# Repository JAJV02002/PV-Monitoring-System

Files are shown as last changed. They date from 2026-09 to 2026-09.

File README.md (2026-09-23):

# ☀️ PV Monitoring System

A photovoltaic monitoring project combining an ESP32 measurement unit, a PHP/MySQL web application, PCB designs and a printable enclosure. Developed for a bachelor’s thesis, the repository brings together the hardware and software resources for studying and recreating the system.





## 🌟 Features

- **Electrical measurements:** RMS voltage, RMS current, apparent power and an accumulated energy estimate.
- **Wi-Fi telemetry:** ESP32 measurements sent to the web application using HTTPS form requests.
- **Web dashboard:** Spanish and English interfaces with charts and historical readings.
- **Device management:** Devices grouped into matrices and measurement points.
- **Hardware resources:** KiCad schematic, board layout, required custom libraries, manufacturing outputs and a PCB assembly model.
- **Printable enclosure:** Separate STL files for the base and lid.

## 📁 Repository Structure

```text
PV-Monitoring-System/
├── hardware/
│   ├── bom/
│   │   └── EMON_BOM.xlsx
│   ├── cad/
│   │   ├── enclosure-base.stl
│   │   └── enclosure-lid.stl
│   └── pcb/
│       ├── kicad/
│       │   ├── monitoring-board.kicad_pro
│       │   ├── monitoring-board.kicad_sch
│       │   └── monitoring-board.kicad_pcb
│       ├── gerber/pcb-manufacturing.zip
│       └── 3d/pcb-assembly.zip
├── software/
│   ├── firmware/
│   │   ├── src/main.cpp
│   │   ├── include/secrets.example.h
│   │   └── platformio.ini
│   └── webapp/
│       ├── app/
│       ├── resources/
│       ├── index.php
│       └── .env.example
└── docs/
    └── architecture.md
```

Each component directory includes its own README with configuration and usage instructions.

## 🚀 Quick Start

### 1. Prepare the Hardware

1. Review the [Excel bill of materials](hardware/bom/EMON_BOM.xlsx).
2. Open the [KiCad project](hardware/pcb/kicad/README.md) and inspect the circuit and board layout.
3. Review the [manufacturing files](hardware/pcb/gerber/README.md) before ordering a PCB.
4. Inspect and print the [enclosure base and lid](hardware/cad/README.md), checking scale and fit against the board.

### 2. Configure the Web Application

Set up Apache, PHP with `mysqli`, and MySQL. Follow the [web application guide](software/webapp/README.md) to configure the document root, HTTPS and database connection.

```sh
cd software/webapp
cp .env.example .env
```

Enter the database credentials and a random hexadecimal device key in `.env`. A compatible database schema is required; the standalone schema is not yet published. See [database requirements](software/webapp/database/README.md).

### 3. Configure and Upload the Firmware

```sh
cd software/firmware
cp include/secrets.example.h include/secrets.h
```

Set the Wi-Fi credentials, HTTPS endpoint and matching device key in `secrets.h`, then build and upload:

```sh
pio run
pio run --target upload
pio device monitor
```

### 4. Connect the Measurement Point

Register the device with the web application, associate it with a measurement point, and confirm that readings appear in the database and dashboard. Check calibration against a suitable reference instrument.

## 📊 System Architecture

```text
Voltage and current signals
            │
            ▼
      ESP32 + sensors
  Sampling · RMS · Calibration
            │
            │ Wi-Fi / HTTPS form POST
            ▼
      PHP web application
    Controllers · Models · Views
            │
            ├── MySQL measurement storage
            │
            ▼
       Web dashboard
   Live views · History · Charts
```

## 🔧 Hardware

The Excel BOM contains core components and a high-precision sensing configuration, including the ESP32-DEVKITC-32E, HCPL-7800A-300E, OP177GSZ and HXS20-NP. Use the workbook as the component list and check compatibility with the intended PCB revision before assembly.

The manufacturing job describes a **two-layer, 1.6 mm board**, approximately **100.4 × 70.4 mm**. The enclosure is available as STL meshes, and the PCB assembly is available as a STEP model.

## 💻 Software Stack

| Component | Technology |
| --- | --- |
| Firmware | C++ / Arduino framework / PlatformIO |
| Microcontroller target | ESP32 development board (`esp32dev`) |
| Backend | PHP with an MVC-style structure |
| Database | MySQL through `mysqli` |
| Web server | Apache |
| Frontend | PHP views, HTML, CSS and JavaScript |
| Interface libraries | Bootstrap, Chart.js, jQuery and Popper |
| Telemetry | HTTPS with URL-encoded form fields |

## 📈 Measurement Details

- **ADC inputs:** GPIO 34 for voltage and GPIO 35 for current.
- **Sampling:** 12-bit resolution, 1,000 samples per block.
- **Averaging:** Voltage and current averaged over five blocks.
- **Power:** Apparent power calculated as `Vrms × Irms`.
- **Energy:** Time-integrated estimate assuming unity power factor; resets at restart.

The offset filter removes the DC component. Calibration and supported electrical ranges must be verified for the measurement hardware. See the [firmware guide](software/firmware/README.md) for timing and power-averaging details.

## 📖 Documentation

- [Hardware guide](hardware/README.md)
- [Bill of materials](hardware/bom/README.md)
- [Firmware setup](software/firmware/README.md)
- [Web application setup](software/webapp/README.md)
- [Database requirements](software/webapp/database/README.md)
- [Architecture and telemetry](docs/architecture.md)

## 📝 License
This project is licensed under the Creative Commons Attribution 4.0 License - see the [LICENSE](LICENSE.txt) file for details.

The web application is distributed under its existing [GNU GPL version 3 license](software/webapp/LICENSE). Third-party libraries retain their own notices. Separate licensing terms for the hardware, firmware and documentation are not yet specified.

## 🤝 Contributing

Improvements to documentation, reproducibility, hardware integration and software testing are welcome. Use repository issues to describe a problem or propose a change, and include the board revision and relevant configuration when reporting results.

## 🎓 Educational Use

The project supports study of embedded acquisition, electrical measurement, wireless telemetry and web-based monitoring in renewable-energy research.

## 🙏 Acknowledgments

- ESP32 and Arduino communities
- KiCad development community
- Bootstrap, Chart.js and other third-party library contributors

---

**Made with ❤️ for renewable energy monitoring**

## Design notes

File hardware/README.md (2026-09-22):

# 🔧 Hardware

PCB designs, enclosure models and component information for the monitoring unit.

## 📁 Files and Directories

| Directory | Contents |
| --- | --- |
| [bom](bom/README.md) | Excel component, quantity and cost tables |
| [cad](cad/README.md) | Enclosure base and lid STL meshes |
| [pcb/kicad](pcb/kicad/README.md) | Editable project, schematic, board layout and required custom libraries |
| [pcb/gerber](pcb/gerber/README.md) | Manufacturing layers and drill files |
| [pcb/3d](pcb/3d/README.md) | PCB assembly STEP model |

## 🚀 Build Preparation

1. Use [EMON_BOM.xlsx](bom/EMON_BOM.xlsx) to plan component purchases.
2. Open the KiCad project to inspect the schematic, footprints and board revision.
3. Review the manufacturing outputs before placing a PCB order.
4. Inspect the enclosure meshes and check their fit against the PCB assembly model.

## 📐 Board Details

The Gerber job specifies two copper layers, a 1.6 mm thickness and an approximate size of 100.4 × 70.4 mm. Check the intended revision and component compatibility before assembly.

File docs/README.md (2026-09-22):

# 📖 Project Documentation

Guides for understanding the monitoring system and recreating its hardware and software setup.

## 🚀 Recommended Reading Order

1. [Hardware](../hardware/README.md): components, enclosure, PCB and manufacturing resources.
2. [Web application](../software/webapp/README.md): Apache, PHP, database and device-key configuration.
3. [Firmware](../software/firmware/README.md): ESP32 configuration, build and upload.
4. [Architecture and telemetry](architecture.md): acquisition flow, request fields and data storage.

## 🔗 Additional Reference

- [Bill of materials](../hardware/bom/README.md)
- [Database requirements](../software/webapp/database/README.md)

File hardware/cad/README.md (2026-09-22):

# 🧩 Enclosure

Two STL meshes define the enclosure base and lid.

## 📁 Files

| File | Description |
| --- | --- |
| [enclosure-base.stl](enclosure-base.stl) | Enclosure base |
| [enclosure-lid.stl](enclosure-lid.stl) | Enclosure lid |

## 🖨️ Printing Preparation

1. Open both meshes in a CAD viewer or slicer.
2. Confirm the scale: STL files do not encode units.
3. Check board clearance and lid fit against the [PCB assembly model](../pcb/3d/README.md).
4. Select printing material, orientation and settings appropriate to the installation.

The files contain mesh geometry; editable parametric enclosure models are not included.

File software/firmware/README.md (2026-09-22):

# ⚡ ESP32 Firmware

ESP32 firmware for acquiring voltage and current signals, calculating electrical measurements and sending them to the web application. The program is in `src/main.cpp`; network credentials and the server URL belong in the local `include/secrets.h` file.

## ⚙️ Configuration

Copy the configuration template:

```sh
cp include/secrets.example.h include/secrets.h
```

Set `SERVER_URL` to your HTTPS endpoint ending in `/app/api.php`. The Apache configuration also accepts the previous `/app/app.php` URL for existing devices. Set `DEVICE_API_KEY` to the same value as the web application's `DEVICE_API_KEY`. Use a random hexadecimal key: the current firmware concatenates form fields without URL encoding, so characters such as `&`, `+` and `=` must not be used in that key.

Set `WIFI_SSID` and `WIFI_PASSWORD` for your local network. The network-selection routine starts with one configured entry. To add networks, define their credentials in the ignored `secrets.h` file and add the corresponding entries to `knownNetworks`.

Never commit `secrets.h`.

## 🚀 Build and Upload

The project targets an ESP32 development board (`esp32dev`) using the Arduino framework. Upload and serial-monitor speeds are both 115200 baud.

```sh
pio run
pio run --target upload
pio device monitor
```

PlatformIO installs the Espressif platform on the first build. Measurements are sent directly to the PHP application using the ESP32 Wi-Fi and HTTP libraries. The platform version is not pinned in `platformio.ini`; record the version used for your build so you can reproduce it later.

## 📈 Measurement Procedure

1. Read voltage on GPIO 34 and current on GPIO 35 with 12-bit ADC resolution.
2. Collect 1,000 samples per block and update the dynamic offset estimates.
3. Accumulate squared offset-corrected samples and calculate RMS values.
4. Apply the existing calibration coefficients and piecewise corrections.
5. Compute apparent power for the current block as `Vrms × Irms`.
6. Integrate that power over elapsed time into an energy estimate in Wh, assuming unity power factor.
7. Average voltage and current over five blocks and transmit the resulting values.

The transmitted power is the value from the final block, not the product of the five-block average RMS values. Energy is accumulated each block and is held only in RAM. It resets at restart. The routine includes a five-second delay after an upload attempt; acquisition and networking add to that interval, so transmission is not on an exact fixed-period schedule.

The ADC offset filter removes the DC component. Calibration coefficients are defined in `src/main.cpp`. Check and adjust them against your measurement hardware and a suitable reference instrument before using the readings.

## 📡 Telemetry

The firmware sends `_np`, `api_key`, `chipid`, `mac`, `voltaje`, `corriente`, `potencia` and `energia` as form fields. See [the protocol description](../../docs/architecture.md).

The HTTPS client calls `setInsecure()`, so it does not verify the server certificate. Configure certificate verification before using it on an untrusted network. An HTTP success response alone does not prove that a reading was stored: the server also uses response bodies for device registration and measurement-point status.

## ✅ Checking Your Build

After uploading, open the serial monitor and check the Wi-Fi connection, device identifier and server response. Associate the device with a measurement point in the web application, then confirm that new readings appear in the database and dashboard. Compare voltage and current readings against your reference instrument before relying on the calibration.

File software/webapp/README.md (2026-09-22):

# 🌐 Monitoring Web Application

A PHP/MySQL application for receiving ESP32 measurements and displaying them in Spanish and English dashboards. Controllers, models and views support authentication, device and measurement-point management, historical readings and statistics.

## 📋 Requirements

- PHP with `mysqli` and session support. The source uses PHP 7.3-or-later language/API features; a supported PHP release should be validated for deployment.
- MySQL and a compatible database schema.
- Apache with `mod_rewrite`, `.htaccess` overrides enabled, and permission to apply the included access restrictions. `mod_headers` enables the configured HTTP headers.
- An HTTPS endpoint reachable by the ESP32.

The standalone database schema and migrations are not yet published. Read [database requirements](database/README.md) before deployment; a compatible database structure is required to run the application.

## ⚙️ Local Configuration

```sh
cp .env.example .env
```

Fill in these values for your own server:

| Variable | Purpose |
| --- | --- |
| `DB_HOST` | MySQL host; defaults to `localhost` |
| `DB_NAME` | Database name |
| `DB_USER` | Database user |
| `DB_PASSWORD` | Database password |
| `DEVICE_API_KEY` | Shared key used by the ESP32 ingestion endpoint |

Use a new random hexadecimal device key and copy the same value into the firmware's local `secrets.h`. Empty or missing device keys are rejected. Database credentials have no embedded deployment defaults.

`app/config.php` loads the optional `.env` file. Existing `$_ENV`, `$_SERVER` or process environment values take precedence. The file supports one `KEY=value` assignment per line, optional matching quotes and full-line `#` comments. It does not expand variables, process escape sequences, or support inline comments. Use `DB_PASSWORD` for the database password.

Keep `.env` private. The included `.htaccess` denies HTTP access to dotfiles, local configuration and database exports. If another web server is used, equivalent restrictions are required; it will not read Apache rules.

## 🛠️ Apache Setup

Point the virtual host document root to this `software/webapp` directory, not to the repository root. The application uses root-relative routes and expects to be hosted at `/`; serving it from a nested URL path requires routing changes.

Enable the rewrite rules and the included access restrictions, then configure HTTPS. Create a compatible database using the schema when it is available, and enter its credentials in the local configuration. The application timezone is set to `America/Mexico_City`; adjust it in `app/api.php` if your installation uses a different timezone.

## 📡 Devices and Measurements

The ESP32 posts to `/app/api.php` with `_np=1` and the shared device key. A previously unseen chip ID creates a device record. Assign the device to a measurement point before expecting readings to be recorded. Once a point is associated with the device, the ingestion path maps the submitted voltage, current, power and energy to the readings model.

See [architecture and field mapping](../../docs/architecture.md) for the protocol.

## ✅ Checking Your Installation

Test the complete measurement path before using the dashboard: authenticate, register a device, associate it with a measurement point, send a reading and confirm that it appears in the history view. Keep database credentials and device keys in local configuration, and check server logs when a request fails. Review access control and database queries before exposing your installation to the Internet.

## 📝 License

This application is distributed under the [GNU General Public License version 3](LICENSE). Third-party libraries retain their own copyright and license notices.

## 📁 File Naming

Source filenames are in English. Model-class mappings in `app/autoloader.php` retain the existing database table names, and browser routes remain compatible with the Spanish and English interfaces.

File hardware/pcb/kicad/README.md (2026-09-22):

# 🛠️ KiCad PCB Design

Editable schematic, board layout and project-local component libraries for the monitoring unit.

## 📁 Project Files

- [monitoring-board.kicad_pro](monitoring-board.kicad_pro): project settings.
- [monitoring-board.kicad_sch](monitoring-board.kicad_sch): circuit schematic.
- [monitoring-board.kicad_pcb](monitoring-board.kicad_pcb): board layout.
- [fp-lib-table](fp-lib-table): project footprint-library registration.
- [sym-lib-table](sym-lib-table): project symbol-library registration.

## 🧩 Component Libraries

| Directory | Contents |
| --- | --- |
| [footprints.pretty](footprints.pretty) | 19 custom footprints, including the two logos placed on the board |
| [symbols](symbols) | 7 custom symbol libraries referenced by the schematic |
| [3dmodels](3dmodels) | 16 component STEP models referenced by the board |

The component selection follows the PCB component references and its design BOM, with the two board-logo footprints included because they are part of the layout. Unused parts, plugins, caches and backups are excluded. The purchasing BOM is [EMON_BOM.xlsx](../../bom/EMON_BOM.xlsx).

## 🚀 Getting Started

1. Install KiCad 8.0 or a compatible newer version with its standard symbol, footprint and 3D-model libraries.
2. Open `monitoring-board.kicad_pro` from this directory.
3. The project library tables resolve custom components through `${KIPRJMOD}`; no personal library-folder path is required.
4. Inspect the schematic, board and 3D view before editing or manufacturing.

Standard KiCad components remain linked to the installed libraries. The custom models in `3dmodels/` use project-relative paths. Keep this directory structure intact when copying the project.

## 🔗 Related Resources

- [Bill of materials](../../bom/README.md)
- [Manufacturing files](../gerber/README.md)
- [PCB assembly STEP model](../3d/README.md)
- [Enclosure meshes](../../cad/README.md)

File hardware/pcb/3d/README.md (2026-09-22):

# 🧊 PCB Assembly Model

[pcb-assembly.zip](pcb-assembly.zip) contains `pcb-assembly.step`, a 3D model of the PCB assembly.

## 🚀 How to Use

1. Extract the ZIP archive.
2. Open `pcb-assembly.step` in a compatible CAD application.
3. Inspect the board and component placement.
4. Compare the assembly with the [enclosure meshes](../../cad/README.md) to check clearance and fit.

## 🔗 Related Files

- [KiCad source files](../kicad/README.md)
- [Enclosure base and lid](../../cad/README.md)

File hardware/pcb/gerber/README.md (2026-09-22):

# 🏭 PCB Manufacturing Files

[pcb-manufacturing.zip](pcb-manufacturing.zip) contains the PCB fabrication outputs.

## 📦 Archive Contents

- Front and back copper layers.
- Front and back silkscreen, solder-mask and solder-paste layers.
- Board outline.
- Plated and non-plated drill files.
- Manufacturing job file with layer references and board specifications.

## 📐 Export Details

| Property | Value |
| --- | --- |
| Export tool | KiCad 8.0.4 |
| Export date | October 23, 2024 |
| Copper layers | 2 |
| Board thickness | 1.6 mm |
| Approximate size | 100.4 × 70.4 mm |

## 🚀 Before Ordering

Extract the archive and inspect all layers and drill files in a Gerber viewer. These outputs represent the export dated above. After changing the KiCad board, regenerate the manufacturing files and confirm fabrication settings before ordering.

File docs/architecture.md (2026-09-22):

# 📊 Architecture and Telemetry

## ⚡ Embedded Acquisition

The ESP32 acquires two analog channels, applies offset removal and calibration, and reports RMS voltage and current. Voltage and current are averaged over five acquisition blocks. Power is the last block's apparent power; the energy accumulator integrates block-level apparent power with a unity-power-factor assumption.

## 📡 Transport

The firmware sends an HTTPS POST to `/app/api.php` with content type `application/x-www-form-urlencoded`.

| Field | Meaning | Server use |
| --- | --- | --- |
| `_np` | Device request marker, value `1` | Selects device ingestion |
| `api_key` | Shared deployment key | Compared with `DEVICE_API_KEY` |
| `chipid` | ESP32 eFuse MAC-derived numeric identifier | `dispositivos.id_chip` |
| `mac` | Wi-Fi MAC address | `dispositivos.mac_address` |
| `voltaje` | Averaged RMS voltage, V | `lecturas.voltaje_RMS` |
| `corriente` | Averaged RMS current, A | `lecturas.corriente_RMS` |
| `potencia` | Final-block apparent power, VA | `lecturas.potencia_aparente` |
| `energia` | Accumulated estimate, Wh | `lecturas.consumo_electrico` |

The body is form data, not JSON. Device identifiers describe the board; the shared key provides the endpoint's device authentication. The firmware currently disables certificate verification.

## 🔄 Server Flow

`app/api.php` validates the device key, then uses `MatrixController` to look up the chip ID. A new chip ID is inserted into `dispositivos`. An existing device must be linked to a record in `puntos`; only then does `ReadingController::captureReading()` store the measurement through the `lecturas` model.

The same request handler serves browser operations. Browser POST requests use a CSRF token. Session handling and remember-me support are defined in the authentication controller and autoloader.

## 🗄️ Storage and Presentation

Models extend the `DB` class, which connects through `mysqli`. The web application keeps its PHP views, CSS and JavaScript under `resources/`. The front controller in `index.php` chooses Spanish or English views according to the URL prefix.

The tables and columns used by the application are described in [database requirements](../software/webapp/database/README.md). A standalone database schema is not yet published; that inventory does not define the column types, constraints and indexes needed for deployment.

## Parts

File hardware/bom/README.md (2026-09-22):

# 📋 Bill of Materials

[EMON_BOM.xlsx](EMON_BOM.xlsx) is the project's bill of materials. The tables below reproduce its component lists for convenient viewing on GitHub.

## 🧩 BOM Organization

The BOM is divided into **common components** and **configuration-specific components**:

- **Common components** form the core monitoring hardware and are shared across the sensing configurations.
- **Configuration-specific components** depend on the selected sensing arrangement. The workbook lists the additional parts for the high-precision configuration.

For a build, combine the common-component table with the parts for the chosen configuration. The workbook remains the editable reference for quantities, suppliers and costs.

## 🔧 Common Components

| Designator | Component / Part Number | Quantity | Unit Cost (USD) | Total Cost (USD) | Supplier |
| --- | --- | ---: | ---: | ---: | --- |
| Power_Ext_5V1 | 640456-2 (2-pin header) | 1 | 0.21 | 0.21 | Mouser |
| C1 | 1000 pF MLCC capacitor | 1 | 0.14 | 0.14 | Mouser |
| C2, C9 | 10 µF electrolytic capacitor | 2 | 0.57 | 1.14 | Mouser |
| C3, C4, C6, C8, C10, C11 | 0.1 µF tantalum capacitor | 6 | 1.16 | 6.96 | Mouser |
| C5, C7 | 200 pF MLCC capacitor | 2 | 0.62 | 1.24 | Mouser |
| C12, C14 | 33 nF MLCC capacitor | 2 | 0.16 | 0.32 | Mouser |
| C13 | 3.3 nF MLCC capacitor | 1 | 0.30 | 0.30 | Mouser |
| LED1, LED2 | Red SMD LED | 2 | 0.99 | 1.98 | Mouser |
| Terminal Block 1x3 | 3-pin screw terminal | 1 | 2.00 | 2.00 | Mouser |
| PS_HV1, PS_LV1 | IV0505S isolated DC/DC converter | 2 | 8.83 | 17.66 | Mouser |
| R1–R18, R_LED1, R_LED2 | Precision resistors (various values) | 20 | — | 8.52* | Mouser |
| TP_GND1–TP_Vy1 | Test points | 11 | 0.34 | 3.74 | Mouser |
| U2_Header | HDR100MET40F-G-V-TH female header | 2 | 3.50 | 7.00 | Mouser |
| U2 | ESP32-DEVKITC-32E | 1 | 13.26 | 13.26 | Mouser |

\* The resistor total is the combined cost of the different resistor values; no single unit price is specified.

## 🎯 Configuration-Specific Components

### High-Precision Sensing Configuration

| Designator | Component / Part Number | Quantity | Unit Cost (USD) | Total Cost (USD) | Supplier |
| --- | --- | ---: | ---: | ---: | --- |
| IC1 | HCPL-7800A-300E isolation amplifier | 1 | 14.64 | 14.64 | Mouser |
| IC2, IC3 | OP177GSZ precision operational amplifier | 2 | 4.08 | 8.16 | Mouser |
| U1 | HXS20-NP current transducer | 1 | 17.10 | 17.10 | Newark |

## 🚀 Purchasing and Assembly

1. Choose the sensing configuration for the build.
2. Use the common components together with the relevant configuration-specific parts.
3. Check footprints, electrical ratings and the intended PCB revision before ordering.
4. Confirm current supplier prices and availability; the listed USD costs are reference figures.

The KiCad project libraries follow the parts referenced by the board design. Selecting those library files does not substitute or modify entries in this Excel BOM.

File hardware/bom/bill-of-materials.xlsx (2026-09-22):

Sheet: Bill of materials for the core
Designator | Component | Qty | Unit cost (USD) | Total cost (USD) | Supplier
 | (Part No.)
Power_Ext_5V1 | 640456-2 (2-pin header) | 1 | 0.21 | 0.21 | Mouser
C1 | 1000 pF MLCC capacitor | 1 | 0.14 | 0.14 | Mouser
C2, C9 | 10 µF electrolytic capacitor | 2 | 0.57 | 1.14 | Mouser
C3, C4, C6, C8, C10, C11 | 0.1 µF tantalum capacitor | 6 | 1.16 | 6.96 | Mouser
C5, C7 | 200 pF MLCC capacitor | 2 | 0.62 | 1.24 | Mouser
C12, C14 | 33 nF MLCC capacitor | 2 | 0.16 | 0.32 | Mouser
C13 | 3.3 nF MLCC capacitor | 1 | 0.3 | 0.3 | Mouser
LED1, LED2 | Red SMD LED | 2 | 0.99 | 1.98 | Mouser
Terminal Block 1x3 | 3-pin screw terminal | 1 | 2 | 2 | Mouser
PS_HV1, PS_LV1 | IV0505S isolated DC/DC converter | 2 | 8.83 | 17.66 | Mouser
R1–R18, R_LED1, R_LED2 | Precision resistors (various values) | 20 | — | 8.52* | Mouser
TP_GND1–TP_Vy1 | Test points | 11 | 0.34 | 3.74 | Mouser
U2_Header | HDR100MET40F-G-V-TH female header | 2 | 3.5 | 7 | Mouser
U2 | ESP32-DEVKITC-32E | 1 | 13.26 | 13.26 | Mouser
* The total cost corresponds to the combined cost of the different resistor values.

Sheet: Bill of materials for the High-
Designator | Component (Part Number) | Qty | Unit cost (USD) | Total cost (USD) | Supplier
IC1 | HCPL-7800A-300E isolation amplifier | 1 | 14.64 | 14.64 | Mouser
IC2, IC3 | OP177GSZ precision operational amplifier | 2 | 4.08 | 8.16 | Mouser
U1 | HXS20-NP current transducer | 1 | 17.1 | 17.1 | Newark
The estimated total cost is 35 – 90 USD, depending on the sensing configuration.

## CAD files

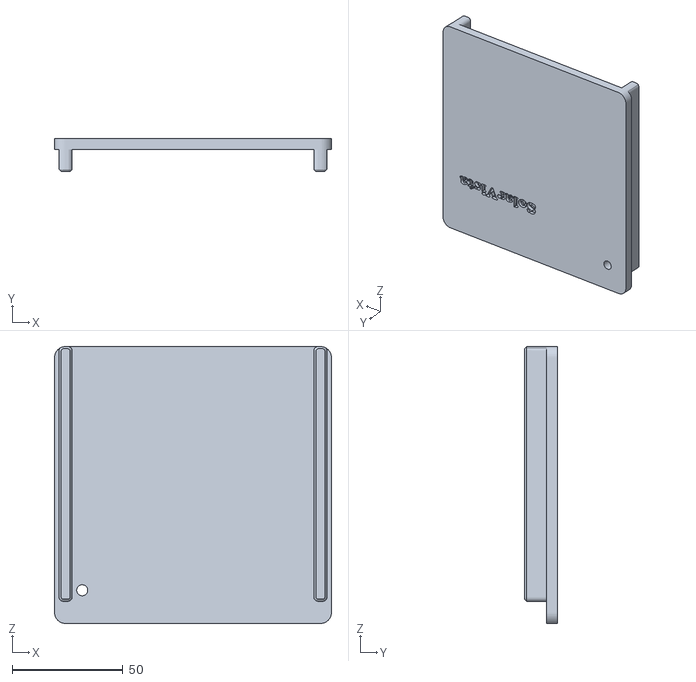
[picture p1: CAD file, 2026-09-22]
hardware/cad/enclosure-lid.stl
125.0 x 15.0 x 125.0

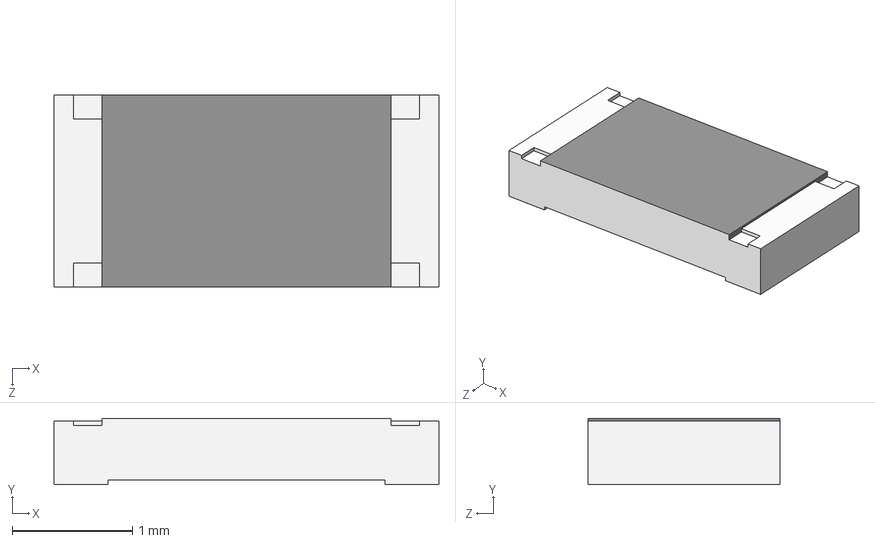
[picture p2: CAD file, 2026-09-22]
hardware/pcb/kicad/3dmodels/resistor-CRCW120610K0FKEAC.step
3.20 x 0.55 x 1.60 mm

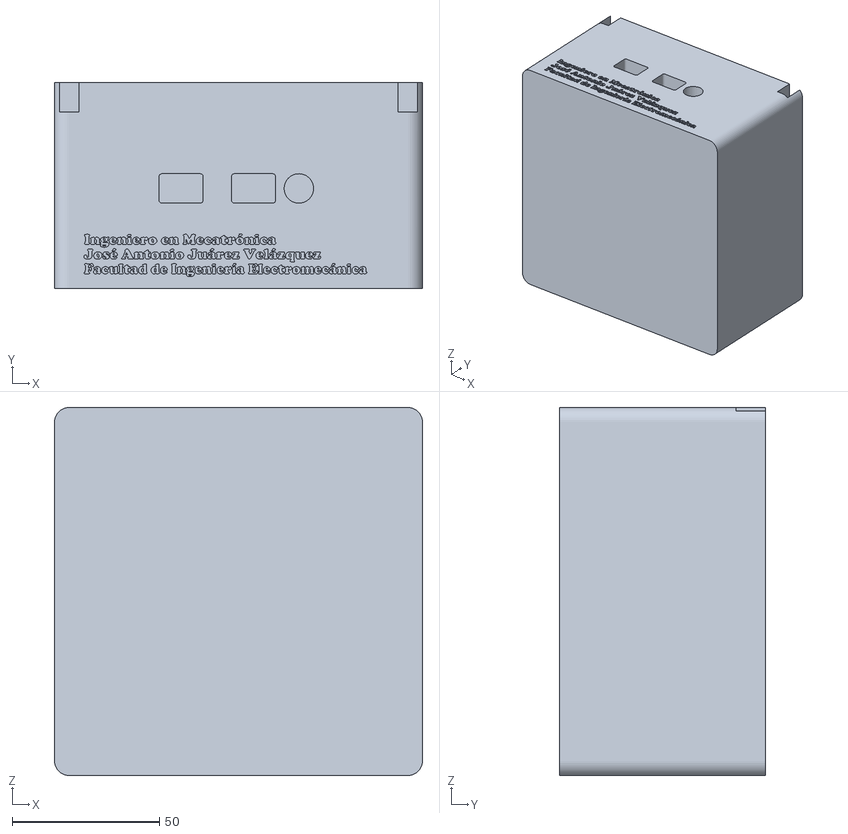
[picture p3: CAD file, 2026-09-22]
hardware/cad/enclosure-base.stl
125.0 x 70.0 x 125.0

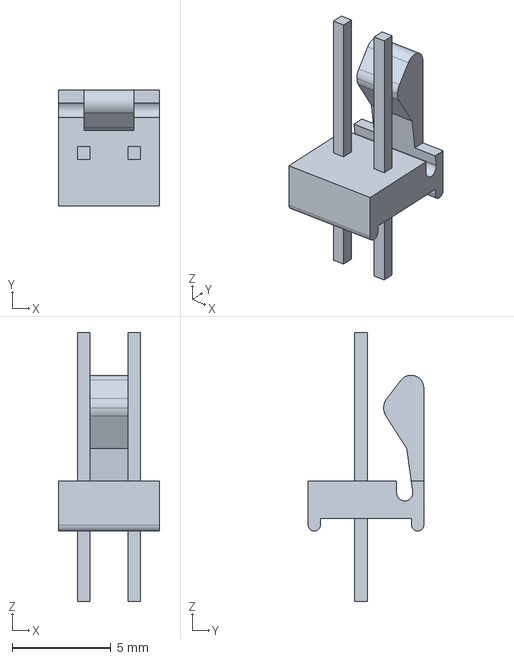
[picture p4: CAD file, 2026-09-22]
hardware/pcb/kicad/3dmodels/header-640456-2.step
5.08 x 5.84 x 13.6 mm

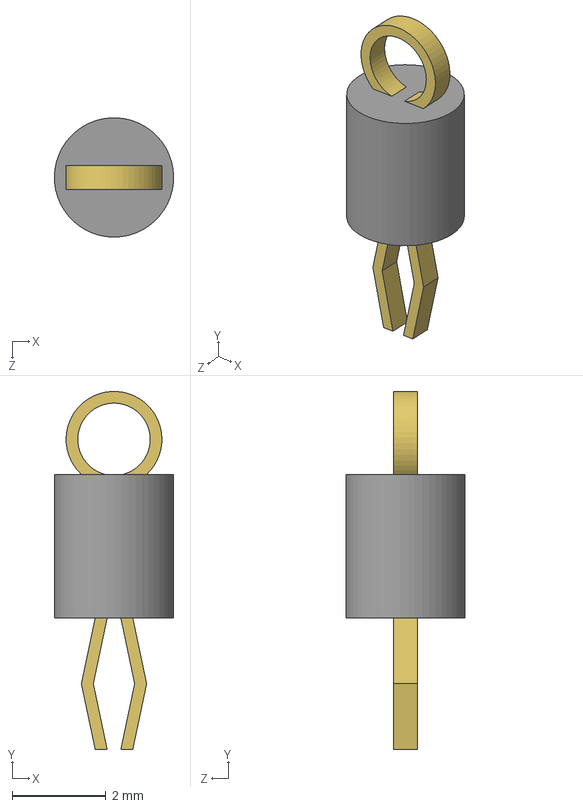
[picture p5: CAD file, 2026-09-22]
hardware/pcb/kicad/3dmodels/test-point-5001.step
2.54 x 7.62 x 2.54 mm

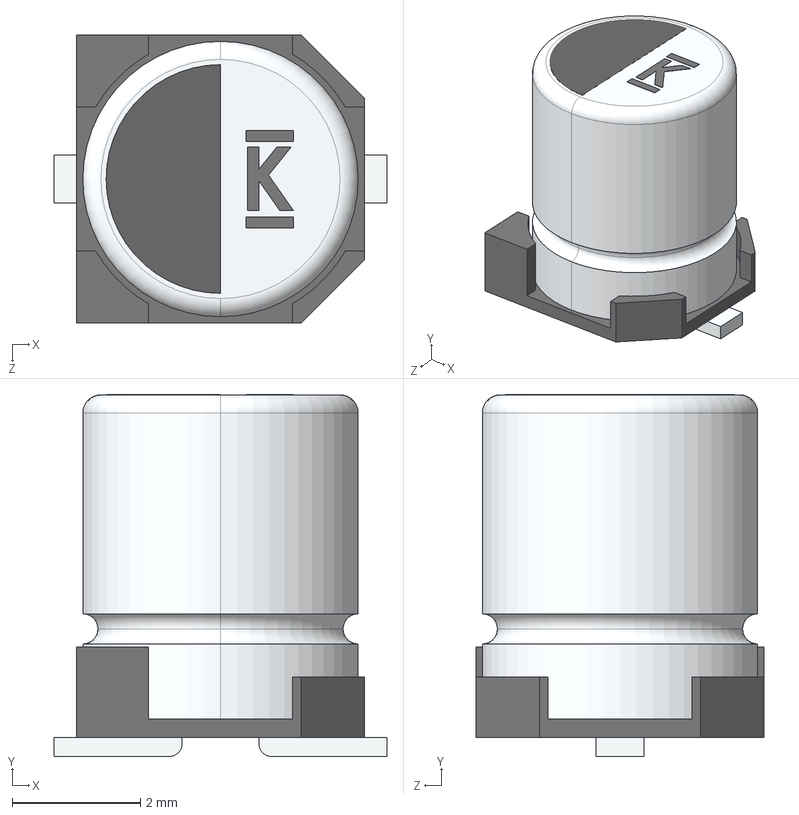
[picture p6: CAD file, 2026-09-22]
hardware/pcb/kicad/3dmodels/capacitor-EXV106M025A9BAA.step
5.20 x 5.66 x 4.50 mm

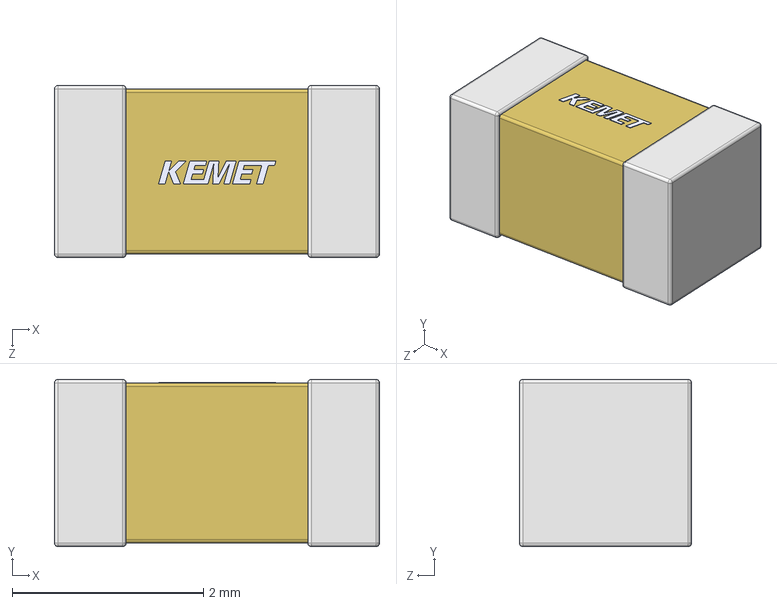
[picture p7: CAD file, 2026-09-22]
hardware/pcb/kicad/3dmodels/capacitor-C1206C201F4HACTU.step
3.40 x 1.75 x 1.80 mm

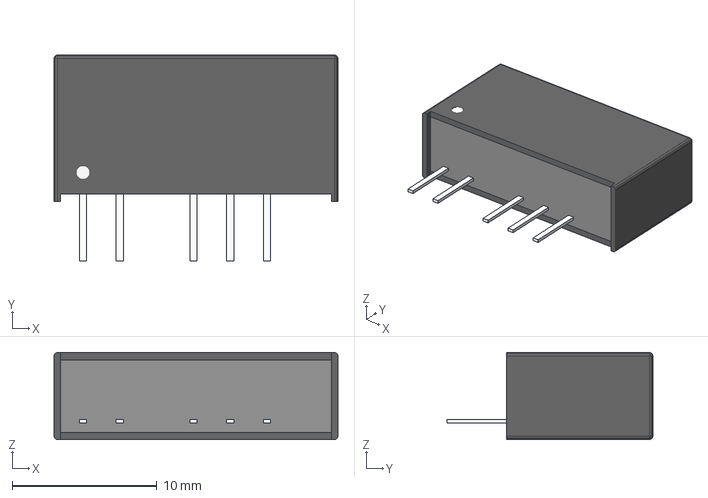
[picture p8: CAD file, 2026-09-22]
hardware/pcb/kicad/3dmodels/RB-0505D.step
19.6 x 14.2 x 6.01 mm

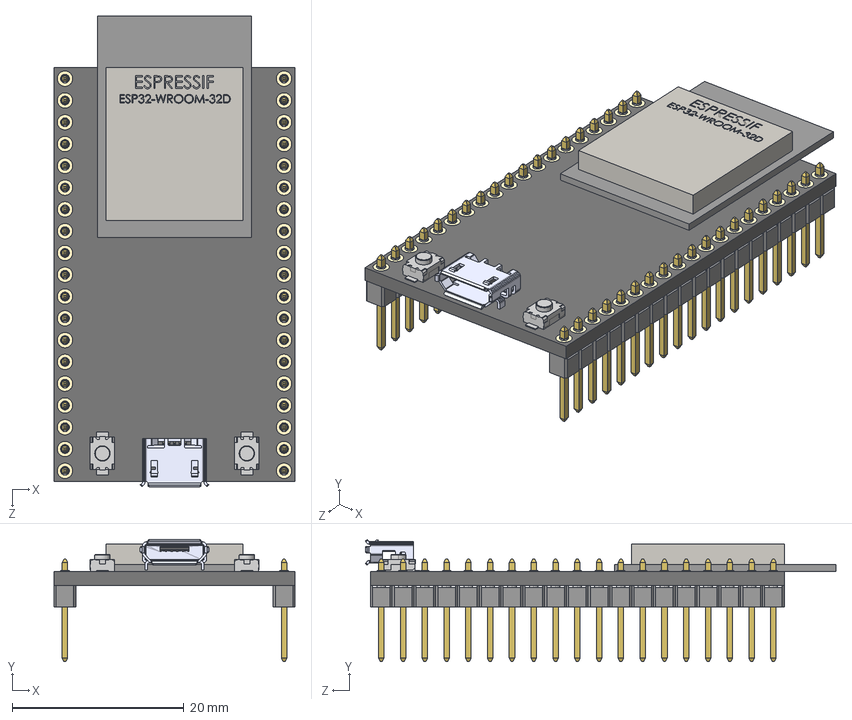
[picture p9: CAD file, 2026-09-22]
hardware/pcb/kicad/3dmodels/ESP32-board.step
28.1 x 14.2 x 54.9 mm
Main-PCB
zl201-19_p2-54_l48-3_w2-54_h8-9 x 2
Soldering-Contacts
ab2_usb_micro_smd.wrl
ESP32-chip
3x4x2mm_tact_button x 2

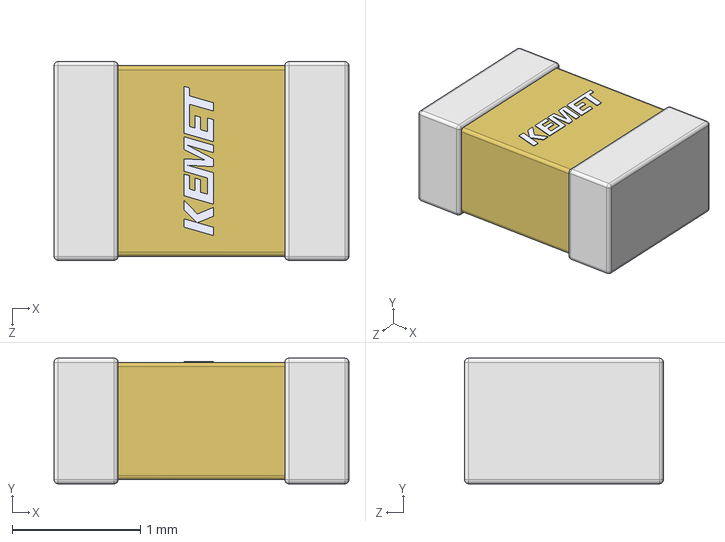
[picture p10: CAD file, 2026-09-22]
hardware/pcb/kicad/3dmodels/capacitor-C0805C332F5GECAUTO7210.step
2.30 x 0.98 x 1.55 mm

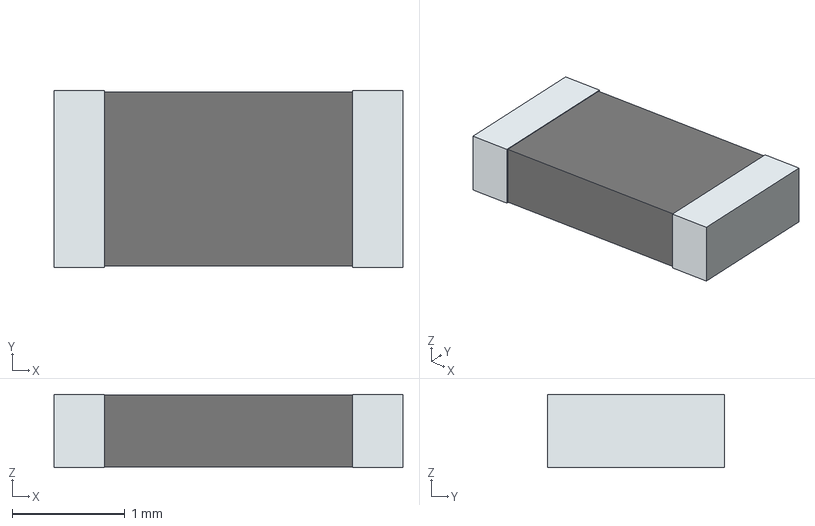
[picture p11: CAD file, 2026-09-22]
hardware/pcb/kicad/3dmodels/resistor-CRGH1206J82K.step
3.10 x 1.57 x 0.65 mm
term1
term2

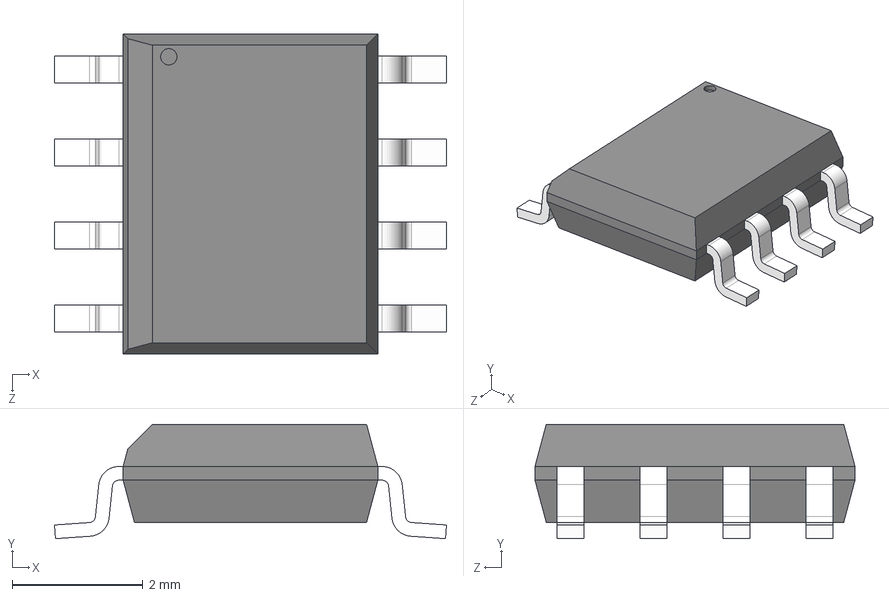
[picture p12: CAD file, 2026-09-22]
hardware/pcb/kicad/3dmodels/OP27GSZ.step
6.00 x 1.75 x 4.90 mm

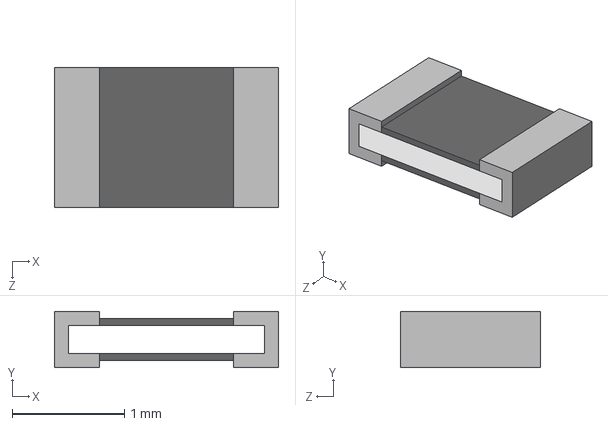
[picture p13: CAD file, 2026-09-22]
hardware/pcb/kicad/3dmodels/resistor-CR0805-FX-3301ELF.step
2.00 x 0.5 x 1.25 mm

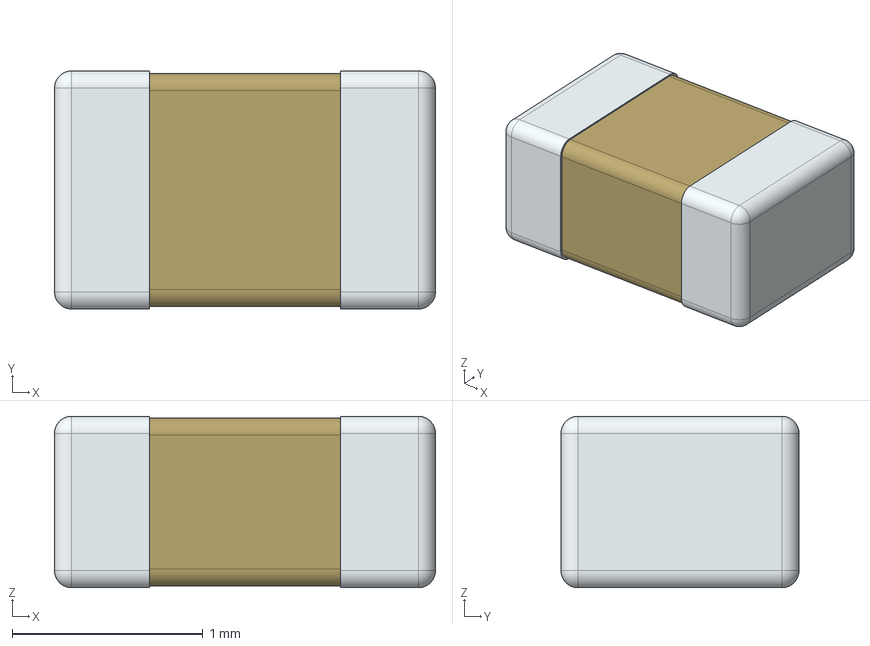
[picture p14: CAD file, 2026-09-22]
hardware/pcb/kicad/3dmodels/capacitor-885012207060.step
2.00 x 1.25 x 0.9 mm

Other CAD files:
hardware/pcb/kicad/3dmodels/resistor-CR1206-FX-1003ELF.step
hardware/pcb/kicad/3dmodels/HXS20-NP.step
hardware/pcb/kicad/3dmodels/HCPL-7800A-300E.step
hardware/pcb/kicad/3dmodels/capacitor-TAJS104K020RNJ.step

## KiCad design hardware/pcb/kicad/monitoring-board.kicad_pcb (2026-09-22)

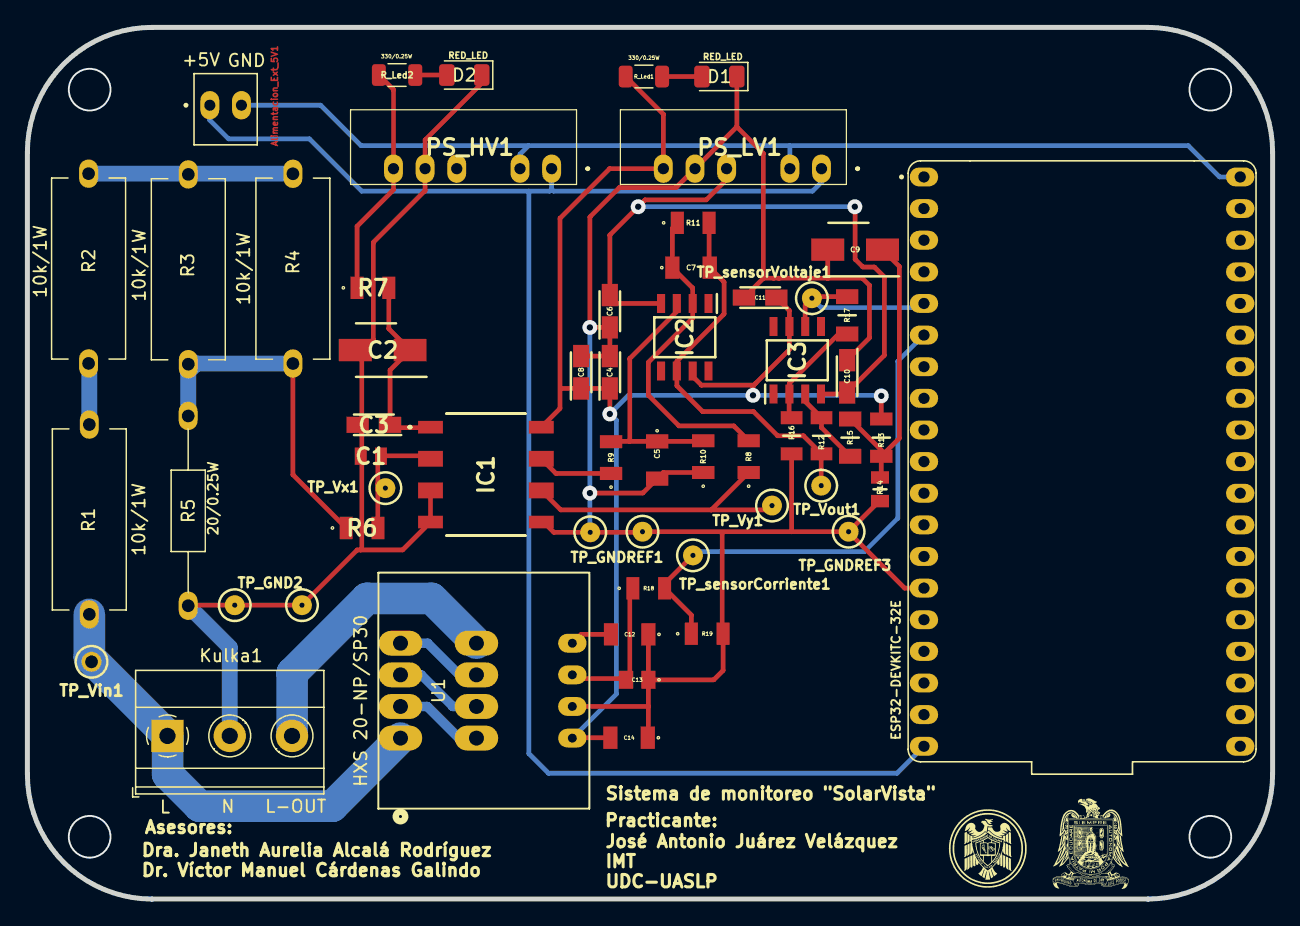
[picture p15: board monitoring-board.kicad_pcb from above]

Board: 2 copper layers, 100.0 x 70.0 mm, 57 parts (0 on the bottom side), 31 nets.

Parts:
Alimentacion_Ext_5V1: 640456-2; header-640456-2
C1: 1000pF/Cer; capacitor-885012207060
C2, C9: 10uF/Elec; capacitor-EXV106M025A9BAA
C3, C4, C6, C8, C10, C11: 0.1uF/Tan; capacitor-TAJS104K020RNJ
C5, C7: 200pF/Cer; capacitor-C1206C201F4HACTU
C12, C14: 33nF/Cer; capacitor-C1206C201F4HACTU
C13: 3.3nF/Cer; capacitor-C0805C332F5GECAUTO7210
D1, D2: RED_LED; LED_1206_3216Metric
IC1: HCPL-7800A-300E
IC2, IC3: OP27GSZ
Kulka1: Screw_Terminal_01x03; TerminalBlock_Phoenix_MKDS-1,5-3_1x03_P5.00mm_Horizontal
PS_HV1: RB-0505D
PS_LV1: RB-0505D
R1, R2, R3, R4: 10k/1W; R_Axial_DIN0614_L14.3mm_D5.7mm_P15.24mm_Horizontal
R5: 20/0.25W; R_Axial_DIN0207_L6.3mm_D2.5mm_P15.24mm_Horizontal
R6, R19: 1k/0.25W; resistor-RCC12061R00FKEA
R7: 1/0.25W; resistor-RCC12061R00FKEA
R8, R9: 39k/0.25W; resistor-RCC12061R00FKEA
R10, R11: 22k/0.25W; resistor-RCC12061R00FKEA
R12, R16: 82k/0.25W; resistor-CRGH1206J82K
R13: 10k/0.25W; resistor-CRCW120610K0FKEAC
R14: 3.3k/0.25W; resistor-CR0805-FX-3301ELF
R15, R17: 100k/0.25W; resistor-CR1206-FX-1003ELF
R18: 1.2k/0.25W; resistor-RCC12061R00FKEA
R_Led1, R_Led2: 330/0.25W; R_1206_3216Metric
TP_GND1, TP_GND2: 5001; test-point-5001
TP_GNDREF1, TP_GNDREF2, TP_GNDREF3: 5001; test-point-5001
TP_Vin1: 5001; test-point-5001
TP_Vout1: 5001; test-point-5001
TP_Vx1: 5001; test-point-5001
TP_Vy1: 5001; test-point-5001
TP_sensorCorriente1: 5001; test-point-5001
TP_sensorVoltaje1: 5001; test-point-5001
U1: HXS 20-NP/SP30; HXS20-NP-SP30
U2: ESP32-DEVKITC-32E

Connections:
+5V_ESP: Alimentacion_Ext_5V1.1, PS_HV1.1 (+VIN), PS_LV1.1 (+VIN), U2.J2_19 (EXT_5V)
/currentSensor_Signal: R18.2, R19.1, TP_sensorCorriente1.1, U2.J2_6 (IO35)
/voltageSensor_Signal: IC3.6 (OUT), R17.2, TP_sensorVoltaje1.1, U2.J2_5 (IO34)
GNDREF: C4.2, C5.2, C6.1, C8.2, C9.2, C10.1, C11.2, C12.1, C13.1, C14.1, D1.1 (K), IC1.5 (GND2), PS_LV1.5 (COM), R10.1, R14.2, R16.1, R19.2, TP_GNDREF1.1, TP_GNDREF2.1, TP_GNDREF3.1, U1.10 (GND), U2.J2_14 (GND_J2_14)
GND_ESP: Alimentacion_Ext_5V1.2, PS_HV1.2 (-VIN), PS_LV1.2 (-VIN), U2.J3_1 (GND_J3_1)
Linea: Kulka1.1, R1.1, TP_Vin1.1, U1.1 (IN)
Linea_out: Kulka1.3, U1.8 (OUT)
unnamed: C9.1, R13.2, R14.1, R15.1
unnamed: C13.2, R18.1, U1.11 (OUT)
unnamed: D1.2 (A), R_Led1.1
unnamed: D2.2 (A), R_Led2.1
unnamed: C2.1, C3.1, IC1.1 (VDD1), R7.2
unnamed: C1.1, IC1.2 (VIN+), R6.2, TP_Vx1.1
unnamed: IC1.7 (VOUT+), R9.1
unnamed: IC1.6 (VOUT-), R8.1, TP_Vy1.1
unnamed: C5.1, IC2.3 (+IN), R9.2, R10.2
unnamed: C7.1, IC2.2 (-IN), R8.2, R11.1
unnamed: C7.2, IC2.6 (OUT), R11.2, R12.1, TP_Vout1.1
unnamed: IC3.3 (+IN), R12.2, R15.2
unnamed: IC3.2 (-IN), R16.2, R17.1
unnamed: R1.2, R2.1
unnamed: R2.2, R3.1, R4.1
unnamed: R3.2, R4.2, R5.1, R6.1
unnamed: U1.2 (OUT), U1.3 (IN)
unnamed: U1.4 (OUT), U1.5 (IN)
unnamed: U1.6 (OUT), U1.7 (IN)
unnamed: C12.2, U1.12 (REF)
Neutro: C1.2, C2.2, C3.2, D2.1 (K), IC1.3 (VIN-), IC1.4 (GND1), Kulka1.2, PS_HV1.5 (COM), R5.2, TP_GND1.1, TP_GND2.1
VDD1: PS_HV1.6 (+VOUT), R7.1, R_Led2.2
VDD2: C4.1, C8.1, C11.1, C14.2, IC1.8 (VDD2), IC2.7 (V+), IC3.7 (V+), PS_LV1.6 (+VOUT), R13.1, R_Led1.2, U1.9 (VC)
VEE: C6.2, C10.2, IC2.4 (V-), IC3.4 (V-), PS_LV1.4 (-VOUT)

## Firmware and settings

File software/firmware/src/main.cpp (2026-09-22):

#include <Arduino.h>
#include <WiFi.h>
#include <WiFiClientSecure.h>
#include <HTTPClient.h>
#include <math.h>
#include "secrets.h"

const char* serverURL = SERVER_URL;
const char* apiKeyValue = DEVICE_API_KEY;

uint64_t chipID = 0;
String macAddr;

const int pinTension = 34;
const int pinCorriente = 35;

const float vRef = 3300.0;
const int resolucionADC = 4095;
const float VCAL = 179.0 / vRef;
const float ICAL = 15 / vRef;
const unsigned int ADC_COUNTS = resolucionADC;

float offsetV = ADC_COUNTS / 3.1;
float offsetI = ADC_COUNTS / 2.9;

float avgV = 0.0;
float avgI = 0.0;
float sumSqV = 0.0;
float sumSqI = 0.0;
unsigned int numMuestras = 1000;

const int numPromedios = 5;
float acumuladorVrms = 0.0;
float acumuladorIrms = 0.0;
float acumuladorVavg = 0.0;
float acumuladorIavg = 0.0;
int contadorPromedios = 0;

float potenciaActiva = 0.0;
float potenciaAparente = 0.0;
float consumoEnergetico = 0.0;
unsigned long tiempoAnterior = 0;

// Diagnostic report counter
unsigned long measurementNumber = 0;

struct WiFiInfo {
    const char* ssid;
    const char* password;
};

const WiFiInfo knownNetworks[] PROGMEM = {
    {WIFI_SSID, WIFI_PASSWORD}
};

void printSeparator() {
    Serial.println(F("------------------------------------------------------------"));
}

void printStartupHeader() {
    Serial.println();
    printSeparator();
    Serial.println(F("eMon Monitoring System - Startup Diagnostics"));
    printSeparator();
}

void printADCInitialization() {
    Serial.println(F("[ADC] ADC subsystem initialized successfully"));
    Serial.print(F("[ADC] Resolution: 12 bits (0-"));
    Serial.print(resolucionADC);
    Serial.println(F(" counts)"));
    Serial.print(F("[ADC] Voltage channel assigned to GPIO "));
    Serial.println(pinTension);
    Serial.print(F("[ADC] Current channel assigned to GPIO "));
    Serial.println(pinCorriente);
    Serial.print(F("[ADC] Samples per calculation: "));
    Serial.println(numMuestras);
}

void printSensorInitialization() {
    Serial.println(F("[SENSORS] Voltage sensor routine initialized"));
    Serial.println(F("[SENSORS] Current sensor routine initialized"));
    Serial.println(F("[SENSORS] Filtering, RMS, calibration and averaging routines ready"));
    Serial.print(F("[SENSORS] Initial voltage offset: "));
    Serial.println(offsetV, 3);
    Serial.print(F("[SENSORS] Initial current offset: "));
    Serial.println(offsetI, 3);
}

void conectarWiFi() {
    WiFi.mode(WIFI_STA);
    Serial.println(F("[Wi-Fi] Searching for a known network..."));

    for (size_t i = 0; i < sizeof(knownNetworks) / sizeof(knownNetworks[0]); ++i) {
        WiFiInfo network;
        memcpy_P(&network, &knownNetworks[i], sizeof(WiFiInfo));

        Serial.print(F("[Wi-Fi] Attempting connection to: "));
        Serial.println(network.ssid);
        WiFi.begin(network.ssid, network.password);

        for (int j = 0; j < 5 && WiFi.status() != WL_CONNECTED; j++) {
            Serial.print('.');
            delay(1000);
        }
        Serial.println();

        if (WiFi.status() == WL_CONNECTED) {
            macAddr = WiFi.macAddress();
            Serial.println(F("[Wi-Fi] Connection successful"));
            Serial.print(F("[Wi-Fi] Connected SSID: "));
            Serial.println(WiFi.SSID());
            Serial.print(F("[Wi-Fi] Local IP address: "));
            Serial.println(WiFi.localIP());
            Serial.print(F("[Wi-Fi] Signal strength: "));
            Serial.print(WiFi.RSSI());
            Serial.println(F(" dBm"));
            return;
        }

        WiFi.disconnect();
        delay(250);
    }

    Serial.println(F("[Wi-Fi][WARNING] No known network could be reached"));
}

void printDeviceInformation() {
    Serial.println(F("[DEVICE] ESP32 identification initialized"));
    Serial.print(F("[DEVICE] Chip ID: "));
    Serial.println((unsigned long long)chipID);
    Serial.print(F("[DEVICE] MAC address: "));
    Serial.println(macAddr);
}

void printWebServiceInitialization() {
    Serial.println(F("[WEB SERVICE] HTTPS communication routine initialized"));
    Serial.print(F("[WEB SERVICE] Endpoint: "));
    Serial.println(serverURL);
    Serial.println(F("[WEB SERVICE] Server and database communication will be verified on the first upload"));
}


void printMeasurementDiagnostics(
    float voltaje,
    float corriente,
    float potencia,
    float energia,
    float Vavg,
    float Iavg,
    int minAdcV,
    int maxAdcV,
    int minAdcI,
    int maxAdcI
) {
    measurementNumber++;
    printSeparator();
    Serial.print(F("[MEASUREMENT] Averaged measurement No. "));
    Serial.println(measurementNumber);

    Serial.print(F("[VALUE] RMS voltage: "));
    Serial.print(voltaje, 3);
    Serial.println(F(" V"));
    Serial.print(F("[VALUE] RMS current: "));
    Serial.print(corriente, 4);
    Serial.println(F(" A"));
    Serial.print(F("[VALUE] Apparent power: "));
    Serial.print(potencia, 3);
    Serial.println(F(" VA"));
    Serial.print(F("[VALUE] Accumulated energy: "));
    Serial.print(energia, 6);
    Serial.println(F(" Wh"));

    Serial.print(F("[VALUE] Filtered average voltage component: "));
    Serial.println(Vavg, 6);
    Serial.print(F("[VALUE] Filtered average current component: "));
    Serial.println(Iavg, 6);

    Serial.print(F("[ADC] Voltage channel range: "));
    Serial.print(minAdcV);
    Serial.print(F(" to "));
    Serial.println(maxAdcV);
    Serial.print(F("[ADC] Current channel range: "));
    Serial.print(minAdcI);
    Serial.print(F(" to "));
    Serial.println(maxAdcI);

}

void sendToServer(
    uint64_t chipID,
    const String& macAddr,
    double voltaje,
    double corriente,
    double potencia,
    double energia
) {
    if (WiFi.status() != WL_CONNECTED) {
        Serial.println(F("[Wi-Fi][WARNING] Connection lost. Attempting reconnection..."));
        conectarWiFi();
    }

    if (WiFi.status() != WL_CONNECTED) {
        Serial.println(F("[UPLOAD][ERROR] Data not sent because Wi-Fi is unavailable"));
        delay(5000);
        return;
    }

    WiFiClientSecure client;
    client.setInsecure();

    HTTPClient http;
    http.setTimeout(8000);

    if (!http.begin(client, serverURL)) {
        Serial.println(F("[UPLOAD][ERROR] HTTPS connection could not be initialized"));
        delay(5000);
        return;
    }

    http.addHeader("Content-Type", "application/x-www-form-urlencoded");

    String postData;
    postData.reserve(220);
    postData = "_np=1";
    postData += "&api_key=";
    postData += apiKeyValue;
    postData += "&chipid=";
    postData += String((unsigned long long)chipID);
    postData += "&mac=";
    postData += macAddr;
    postData += "&voltaje=";
    postData += String(voltaje, 3);
    postData += "&corriente=";
    postData += String(corriente, 4);
    postData += "&potencia=";
    postData += String(potencia, 3);
    postData += "&energia=";
    postData += String(energia, 6);

    Serial.println(F("[UPLOAD] Sending measurement to the web application..."));
    int httpResponseCode = http.POST(postData);

    if (httpResponseCode > 0) {
        String response = http.getString();
        Serial.print(F("[UPLOAD] HTTP response code: "));
        Serial.println(httpResponseCode);
        Serial.print(F("[UPLOAD] Server response: "));
        Serial.println(response);

        if (httpResponseCode >= 200 && httpResponseCode < 300) {
            Serial.println(F("[UPLOAD] Web service and database upload verified successfully"));
        } else if (httpResponseCode == 401) {
            Serial.println(F("[UPLOAD][ERROR] API key rejected by the server"));
        } else if (httpResponseCode == 403) {
            Serial.println(F("[UPLOAD][ERROR] Request rejected by server security validation"));
        } else if (httpResponseCode >= 500) {
            Serial.println(F("[UPLOAD][ERROR] Internal server or database-processing error"));
        } else {
            Serial.println(F("[UPLOAD][WARNING] Server received the request but did not accept the reading"));
        }
    } else {
        Serial.print(F("[UPLOAD][ERROR] HTTPS request failed: "));
        Serial.println(http.errorToString(httpResponseCode));
    }

    http.end();
    delay(5000);
}

void setup() {
    Serial.begin(115200);
    delay(1000);

    printStartupHeader();
    chipID = ESP.getEfuseMac();

    analogReadResolution(12);
    printADCInitialization();
    printSensorInitialization();

    tiempoAnterior = millis();
    conectarWiFi();

    if (macAddr.length() == 0) {
        macAddr = WiFi.macAddress();
    }

    printDeviceInformation();
    printWebServiceInitialization();
    printSeparator();
    Serial.println(F("[SYSTEM] Startup initialization completed"));
    Serial.println(F("[SYSTEM] Beginning sensor acquisition and diagnostic reporting"));
    printSeparator();
}

void loop() {
    sumSqV = 0.0;
    sumSqI = 0.0;
    avgV = 0.0;
    avgI = 0.0;

    int minAdcV = resolucionADC;
    int maxAdcV = 0;
    int minAdcI = resolucionADC;
    int maxAdcI = 0;

    for (unsigned int n = 0; n < numMuestras; n++) {
        int lecturaADC_Tension = analogRead(pinTension);
        int lecturaADC_Corriente = analogRead(pinCorriente);

        if (lecturaADC_Tension < minAdcV) minAdcV = lecturaADC_Tension;
        if (lecturaADC_Tension > maxAdcV) maxAdcV = lecturaADC_Tension;
        if (lecturaADC_Corriente < minAdcI) minAdcI = lecturaADC_Corriente;
        if (lecturaADC_Corriente > maxAdcI) maxAdcI = lecturaADC_Corriente;

        offsetV += (lecturaADC_Tension - offsetV) / 512.0;
        float filteredV = lecturaADC_Tension - offsetV;
        offsetI += (lecturaADC_Corriente - offsetI) / 512.0;
        float filteredI = lecturaADC_Corriente - offsetI;

        float sqV = filteredV * filteredV;
        float sqI = filteredI * filteredI;
        sumSqV += sqV;
        sumSqI += sqI;
        avgV += filteredV;
        avgI += filteredI;
    }

    float rmsV = sqrt(sumSqV / numMuestras);
    float rmsI = sqrt(sumSqI / numMuestras);
    float Vavg = avgV / numMuestras;
    float Iavg = avgI / numMuestras;

    float Vrms = (rmsV * VCAL * (vRef / 1000.0));
    float Irms = rmsI * ICAL * (vRef / 1000.0);
    Vavg = Vavg * VCAL * (vRef / 1000.0);
    Iavg = Iavg * ICAL * (vRef / 1000.0);

    if (Vrms <= 5) Vrms *= 0.7185;
    else if (Vrms <= 10) Vrms *= 1.0391;
    else if (Vrms <= 19.79) Vrms *= 1.007;
    else if (Vrms <= 29.76) Vrms *= 1.0192;
    else if (Vrms <= 39.72) Vrms *= 1.0311;
    else if (Vrms <= 49.68) Vrms *= 1.0286;
    else if (Vrms <= 59.64) Vrms *= 1.0310;
    else if (Vrms <= 69.6) Vrms *= 1.0339;
    else if (Vrms <= 79.56) Vrms *= 1.0366;
    else if (Vrms <= 89.52) Vrms *= 1.0367;
    else if (Vrms <= 99.48) Vrms *= 1.0391;
    else if (Vrms <= 109.44) Vrms *= 1.0420;
    else if (Vrms <= 119.4) Vrms *= 1.0192;
    else if (Vrms <= 127) Vrms *= 1.0391;
    else if (Vrms > 127) Vrms *= 1.0414;

    if (Irms <= 0.245) Irms *= 0.6632;
    else if (Irms <= 0.493) Irms *= 0.8382;
    else if (Irms <= 0.737) Irms *= 0.8714;
    else if (Irms <= 0.981) Irms *= 0.8933;
    else if (Irms <= 1.472) Irms *= 0.9033;
    else if (Irms <= 1.964) Irms *= 0.9088;
    else if (Irms <= 2.471) Irms *= 0.9325;
    else if (Irms <= 2.96) Irms *= 0.9388;
    else if (Irms <= 3.463) Irms *= 0.9439;
    else if (Irms <= 3.961) Irms *= 0.9483;
    else if (Irms <= 4.463) Irms *= 0.9519;
    else if (Irms <= 4.961) Irms *= 0.9650;
    else if (Irms <= 5.463) Irms *= 0.9676;
    else if (Irms <= 5.961) Irms *= 0.9689;
    else if (Irms <= 6.463) Irms *= 0.9621;
    else if (Irms <= 6.8) Irms *= 0.9139;

    potenciaAparente = Vrms * Irms;
    potenciaActiva = potenciaAparente;

    unsigned long tiempoActual = millis();
    float tiempoTranscurridoHoras = (tiempoActual - tiempoAnterior) / 3600000.0;
    consumoEnergetico += potenciaActiva * tiempoTranscurridoHoras;
    tiempoAnterior = tiempoActual;

    acumuladorVrms += Vrms;
    acumuladorIrms += Irms;
    acumuladorVavg += Vavg;
    acumuladorIavg += Iavg;
    contadorPromedios++;

    if (contadorPromedios == numPromedios) {
        Vrms = acumuladorVrms / numPromedios;
        Irms = acumuladorIrms / numPromedios;
        Vavg = acumuladorVavg / numPromedios;
        Iavg = acumuladorIavg / numPromedios;

        acumuladorVrms = 0.0;
        acumuladorIrms = 0.0;
        acumuladorVavg = 0.0;
        acumuladorIavg = 0.0;
        contadorPromedios = 0;

        float voltaje = Vrms;
        float corriente = Irms;
        float potencia = potenciaAparente;
        float energia = consumoEnergetico;

        printMeasurementDiagnostics(
            voltaje, corriente, potencia, energia,
            Vavg, Iavg,
            minAdcV, maxAdcV, minAdcI, maxAdcI
        );

        sendToServer(chipID, macAddr, voltaje, corriente, potencia, energia);
    }
}

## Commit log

2026-09-22 Add ESP32 firmware, PHP web application and project documentation
2026-09-22 Add hardware design files and BOM; remove project status document
    [EMON_BOM.xlsx, PCB_BOM.csv, base_carcasaTarjetaMonitorFV.STL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]
2026-09-22 Write reproduction guides in first person and use the Excel BOM
    [PCB_BOM.csv]
2026-09-22 Restyle project documentation and standardize English filenames
    [bill-of-materials.xlsx, enclosure-base.stl, enclosure-lid.stl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]
2026-09-22 Add project KiCad libraries and publish BOM tables
    [EMON_BOM.xlsx, ESP32-board.step, HXS20-NP.step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]

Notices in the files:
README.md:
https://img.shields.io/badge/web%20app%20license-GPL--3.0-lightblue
